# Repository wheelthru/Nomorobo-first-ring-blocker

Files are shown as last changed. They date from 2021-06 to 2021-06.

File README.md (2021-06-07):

# First-ring blocker for Nomorobo

This tool blocks the first ring of all incoming calls, avoiding the annoying one-ring-and-silence from calls the great Nomorobo service blocks. This is at the cost of real callers having to wait one extra ring before we pick up.  Oh Well.

## Description

The real documentation of this project is here: [http://jimlaurwilliams.org/wordpress/?p=6738](http://jimlaurwilliams.org/wordpress/?p=6738) 

Its ATtiny85 basically controls a normally closed relay in series with the incoming phone line (here a VOIP ATA), opening the contacts a few milliseconds into the first ring, before phones can ring.  It reconnects quickly after the first ring, in hopes of not screwing with the Caller ID sent between rings.

This was built and tuned for my situation, with parts from my junkbox, and probably isn't a drop-in for anybody else.  OK, maybe if they have a Arris TG1682G modem providing their VOIP phone connections.  It was posted here at the request of someone who saw the post in my Project Notes.

The Eagle (7.7.0) files for the PCB I made up for mine are included here.  Unless your junkbox contains the same parts as mine, the board layout probably isn't useful.

Code for the ATtiny85 on the PCB, developed with Arduino IDE 1.8.x, is  in **Nomorobo85Msg.ino**.  A Nano displays stats (rings, blocks) on a 1620 LCD.  Serial communication from the main PCB (via SoftwareSerial) tells the Nano what to show.  The Nano's code is **LcdHostNanoMsg1.ino**.  There are various comments and historical leftovers in both those files.

## Author

Jim Williams (a member of [Workshop88](http://workshop88.com))

## Acknowledgments

Inspired as an improvement on the very useful [Nomorobo](https://www.nomorobo.com/) service.

Special thanks to Aaron Foss for the cool Nomorobo T shirt!

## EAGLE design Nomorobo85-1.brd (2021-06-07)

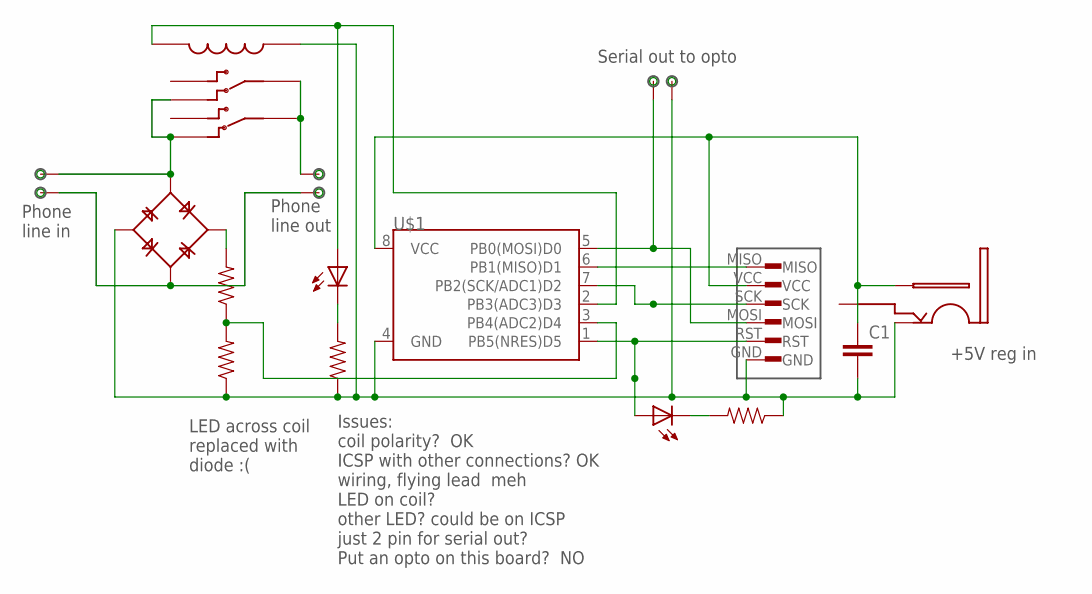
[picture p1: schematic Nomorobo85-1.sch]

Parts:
C1: CAP1206; 1206
U$1: ATTINY85SO08-I-HAVE-THESE; SO08-EIAJ
U$2, U$3, U$4, U$9: RESISTOR1206WW; 1206WW
U$5: BRIDGE-ROUNDMY-600V-1A; BRIDGE-ROUND
U$6: M2X3-HEADERICSP-LONGPADS; M2X3-LONGPADS
U$7, U$8: SOLDER-PAD-2LONGPADS; 02P
U$10: BARREL-COAX-PWR; BARREL-COAX-CONNECTOR
U$11, U$14: LED-12061206; 1206W
U$12: RELAY-DPDT
U$13: SOLDER-PAD-2LONGPPAD2; SOLDER-PAD-2-LONGPADS

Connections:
GND: C1.2, U$1.4 (GND), U$2.1, U$4.1, U$5.OUT- (V-), U$6.GND, U$9.1, U$10.SHELL, U$12.COIL+, U$13.P$2
unnamed: U$1.1 (PB5(NRES)D5), U$6.RST, U$14.1 (A)
unnamed: U$5.AC1 (IN1), U$7.1, U$12.NC1, U$12.NC2
unnamed: U$1.5 (PB0(MOSI)D0), U$6.MOSI, U$13.P$3
unnamed: U$1.2 (PB3(ADC3)D3), U$11.1 (A), U$12.COIL-
unnamed: U$1.6 (PB1(MISO)D1), U$6.MISO
unnamed: U$8.2, U$12.COM1, U$12.COM2
unnamed: U$1.3 (PB4(ADC2)D4), U$3.1, U$4.2
unnamed: U$3.2, U$5.OUT+ (V+)
unnamed: U$9.2, U$11.2 (C)
unnamed: U$5.AC2 (IN2), U$7.2, U$8.1
unnamed: U$2.2, U$14.2 (C)
unnamed: U$1.7 (PB2(SCK/ADC1)D2), U$6.SCK
VCC: C1.1, U$1.8 (VCC), U$6.VCC, U$10.PIN

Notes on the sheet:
Serial out to opto
+5V reg in
Phone line in
Phone line out
Issues: coil polarity? OK ICSP with other connections? OK wiring, flying lead meh LED on coil? other LED? could be on ICSP just 2 pin for serial out? Put an opto on this board? NO
LED across coil replaced with diode :(

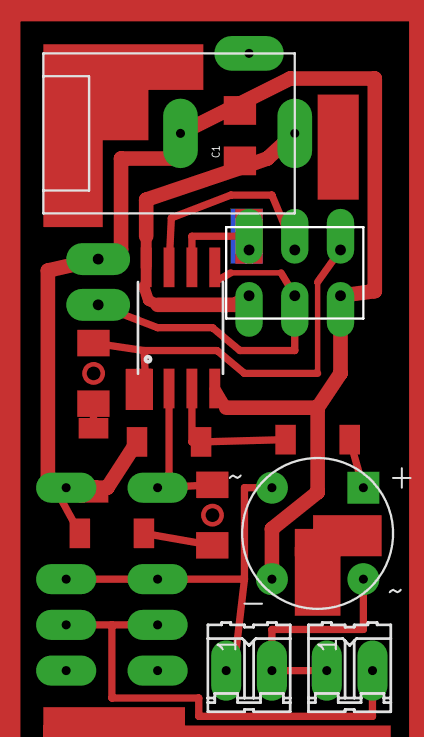
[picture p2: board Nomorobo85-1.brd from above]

Board: 2 copper layers, 15 parts (1 on the bottom side), 14 nets.

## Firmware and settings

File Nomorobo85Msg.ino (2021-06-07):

/* Nomorobo first ring stopper  started 12/30/19
 *  Production version, hosted on Tiny85.
 *  Operates a relay to disconnect all house phones
 *  on first ring.  If NMR blocks a call, we'll never hear
 *  anything.  If it lets the call thru, we need to look
 *  right away, just like in the old days.
 *  
 *  This is designed for our VOIP phones, with 2.0 sec
 *  of 20Hz 90VAC ring on top of 48VDC, 4 sec off.  We turn on
 *  a relay to open the line to the rest of the house phones as
 *  soon as we detect a ring - a few ms.  We watch each half cycle
 *  of the ring (full wave rectified thru a bridge) and detect 
 *  end of ring when we're not retriggered in 25ms or so.
 *  
 *  After first ring is over the NC relay is released, reconnecting
 *  all the house phones.  While that lets caller ID thru, since
 *  phones didn't hear a ring, they're not listening for caller ID
 *  until the next ring.
 *  
 *  Voltage divider (33K/1.5K) is set for 2.56V reference.
 *  
 *  The analog in line can be in one of 3 states:
 *  - 48V, on hook, idle
 *  - ringing: A/D 1023 ~15ms, < THRESH ~10ms
 *  - ~10V, off hook
 *  
 *  There's a ~4ms glitch of ~60V (enough to look like a ring) going from 
 *  off hook to on hook.  We have to protect against that being interpreted
 *  as a ring.  It would look like a NMR one ringer, and get a false count.
 *  
 *  The state machine has 3 states:
 *  - WAITING: 99% of time here.  48VDC, waiting for first ring
 *  - FIRSTRING: line voltage > THRESH within last 35ms, relay open
 *  - HOLDOFF: relay closed, won't retrigger and reopen relay; blue LED on;
 *    exit this state with continuous 5 sec idle.
 * ------------------------------------------------
 * Tiny85 version also counts rings and blocks and sends those stats out via
 * 1200B software serial to an opto isolated input on a 485 net node.  Because
 * the opto is an inverter, we use Software Serial's optional last param to invert.
 * Protocol is modeled after Basement Watchdog Big Dog voltage monitor:
 * - 0x55 header
 * - one byte # rings this message
 * - one byte # blocks this message
 * - one byte checksum
 * 
 * As an interim implementation, it sends ASCII text with some privately
 * defined controls to another Arduino that runs an LCD for display.  A few
 * lines of code change (in one function) and it will talk to a 485 node
 * thru the isolator.  Real Soon Now.
 * 
 * Nomorobo85Msg: changes from strings to formatted message 1/10/20 - works
 */

#include <jim.h>
#include <SoftwareSerial.h>


// hardware pin definitions
#define INPIN A2
#define RELAY 3
#define BLUELED 2
#define TXPIN 0
#define DONTCARE 1
#define HEADER (0x55)

// A/D min value if ringing 
#define THRESH 1020
// A/D max value if off hook
#define OFFHOOKVAL 400
// worst case time since last ring before declaring ring done, ms
#define RINGSTOPPED 35
// escape from HOLDOFF if idle continuously for this long
#define HOLDOFFTIME 5000

  SoftwareSerial myserial(DONTCARE,TXPIN,0);  // last param=1 to invert thru opto


void setup() {
  pinMode (BLUELED, OUTPUT);
  blink(BLUELED,20);
  delay(100);
  blink(BLUELED,20);
  pinMode(RELAY,OUTPUT);
  analogReference(INTERNAL2V56_NO_CAP);  // 2.56V on Tiny85
  myserial.begin(1200);
  //myserial.println("hello");

}// end setup


  enum l {idle,ring,offhook}line;
  int rings=0,nmrblocks=0;


//=============== MAIN LOOP =================
void loop() {
  long currmillis,lastring,lastspin,holdstart;
  int val,oldval=848;
  enum states {WAITING=0,FIRSTRING=1,HOLDOFF=2} state;
  bool morerings,doannounce; // true if ring during holdoff, if announce when done

  state=WAITING;
  
  while(1){
    currmillis=millis();
    // reduce noise with rolling average
    val=(analogRead(INPIN)+(oldval*5)+3)/6;
    oldval=val;
    // assign physical state of line
    line=idle;
    if(val>THRESH)line=ring;
    if(val<OFFHOOKVAL)line=offhook;
    
    //------ HANDLE DETECTED RING: VOLTAGE > THRESH ----
    if(line==ring){
      switch (state){
        case WAITING: // waiting for a ring - got one!
          digitalWrite(RELAY,HIGH); // block that ring!
          state=FIRSTRING;
          lastring=currmillis;    // need to know time since last ring pulse
          rings++;        // fact
          nmrblocks++;    // optimistic guess; fix later if wrong
          morerings=FALSE;  // don't count as NMR block if more rings
          break;
          
        case FIRSTRING: //actively in first ring
          lastring=currmillis;  // reset retrigger timer
          break;
          
        case HOLDOFF: // relay closed again
          morerings=TRUE;   // only matters if doannounce is true
          holdstart=currmillis; // reset timer
          break;
        default:
        ;
      }//end switch
     }//end if ringing; continue below with else not ringing


     //------ HANDLE VOLTAGE BELOW THRESH ------
     // could be idle, offhook, or a voltage dip during active ringing
     else { // idle OR offhook
      switch(state){
        case WAITING:   
          // Offline has a HV glitch when going onhook, so we just use HOLDOFF
          // so that glitch isn't perceived as a ring.
          if(line==offhook){
            state=HOLDOFF;
            doannounce=FALSE;
            holdstart=currmillis; //reset timer
            digitalWrite(BLUELED,HIGH);
          }//end if offhook
          // else boring 99% case
          break;
          
        case FIRSTRING:
          //Check for done ringing with timeout of > 1/2 positive cycle time
          if(currmillis-lastring > RINGSTOPPED){
            digitalWrite(RELAY,LOW);  // main reconnect
            state=HOLDOFF;  // don't detect ring until back to WAITING
            holdstart=currmillis; //reset timer
            doannounce=TRUE;  // only announce if we come in this way
            digitalWrite(BLUELED,HIGH); // visible indication of HOLDOFF state
            }//end if > RINGSTOPPED
            break;
            
        case HOLDOFF:
          // only way out is HOLDOFFTIME in idle state
          if(ring==offhook){holdstart=currmillis;}  // reset
          if(currmillis-holdstart > HOLDOFFTIME){
            state=WAITING;
            digitalWrite(BLUELED,LOW);
            if(doannounce){
              doannounce=FALSE;
              if(morerings)nmrblocks--;
              //announce(); //called in spinner
              }//end if doannounce
          }//end if > HOLDOFFTIME
            break; 
     }//end switch      
   }//end else voltage not > THRESH
      

    // SPINNER
    // was animate remote LCD
    // now, send data
    if(currmillis-lastspin > 2000){
     lastspin=currmillis+1;
     announce();
     //myserial.print('#');
   }//end lastspin
      
     
  }//end while
  
}// end loop()
//================================================



void blink(int pin,long dur){
  digitalWrite(pin,HIGH);
  delay(dur);
  digitalWrite(pin,LOW);  
}


// routine to annouce ring counts
void announce(){
// this is for messages
#if 1
  byte sum,b1,b2,b3,b4;
  b1=rings&0xff;
  b2=rings>>8;
  b3=nmrblocks&0xff;
  b4=nmrblocks>>8;
  myserial.write(HEADER);
  myserial.write(b1);
  myserial.write(b2);
  myserial.write(b3);
  myserial.write(b4);
  sum=b1+b2+b3+b4;  // sum is only a byte, so auto truncates
  myserial.write(sum);
  myserial.write(0xa);
#endif

// this is for remote LCD
#if 0
  myserial.print("$Rings: ");
  myserial.print(rings);
  myserial.print("&NMR blocks: ");
  myserial.print(nmrblocks);
#endif
  
// This one's for the local LCD
#if 0
    lcd.home();
    lcd.clear();
    lcd.print("Rings: ");
    lcd.print(rings);
    lcd.setCursor(0, 1);
    lcd.print("NMR blocks: ");
    lcd.print(nmrblocks);  
#endif

}// end announce

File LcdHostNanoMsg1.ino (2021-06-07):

/* Quickie standalone Arduino to receive messages from
 * NMR first ring stopper and display on LCD.  Uses custom
 * chars for cursor/clear control
 * 1/6/20
 * LcdHostNanoMsg1: 
 * Added protocol for serial message from NMR controller 1/10/20  works
*/

#include <LiquidCrystal_PCF8574.h>
#include <Wire.h>

LiquidCrystal_PCF8574 lcd(0x27); // set the LCD address to 0x27 for a 16 chars and 2 line display

#define HEADER (0x55)
int rings,nmrblocks;

int show = -1;

void setup()
{
  int error;

  Serial.begin(1200);
  //Serial.println("LCD...");


  // See http://playground.arduino.cc/Main/I2cScanner how to test for a I2C device.
  Wire.begin();
  Wire.beginTransmission(0x27);
  error = Wire.endTransmission();

  if (error == 0) {
    Serial.println(": LCD found at 0x27.");
    show = 0;
    lcd.begin(16, 2); // initialize the lcd

  } else {
    Serial.println(": LCD not found.");
  } // if

} // setup()


void loop()
{
  char blank16[]="                ";
  int bits[]={0,0x10,0x8,0x4,0x2,0x1,0x0,0},i;
  lcd.createChar(1,bits); // backslash at char pos 1
  char hbchar[]={'|','/','-',char(1)};
  static char errcnt='0';

    lcd.setBacklight(255);
    lcd.home();
    lcd.clear();
    lcd.print("Nomorobo LCD");
    delay(1000);

  while(1){
    int getvalret=getval();
    if(getvalret==-1)errcnt++;
    if(getvalret==1){
      lcd.setCursor(0,0);
      lcd.print(blank16);
      lcd.setCursor(0,0);
      lcd.print("rings: ");
      lcd.print(rings);
      
      lcd.setCursor(0,1);
      lcd.print(blank16);
      lcd.setCursor(0,1);
      lcd.print("NMR blocks: ");
      lcd.print(nmrblocks);
      
      lcd.setCursor(15,0);
      lcd.print(errcnt);
      lcd.setCursor(15,1);
      lcd.print(hbchar[i++]);
      if(i>3)i=0;
    }// end if got msg
    
  }//end while

  
} // loop()



//--------- READ NMR MESSAGE ---------
// return: -1=err; 0=nothing available; 1=got data
int getval(){
  static byte state=0;
  byte val;

  while(Serial.available()){
    val=Serial.read(); 
    switch(state){
      case 0: if(val==0x55)state=1; // waiting for header
      break;
      case 1: rings=val;  //got rings
        state=2;
        break;
      case 2: rings+=val<<8; // got nmrblocks
        state=3;
        break;
      case 3: nmrblocks=val;  //got rings
        state=4;
        break;
      case 4: nmrblocks+=val>>8; // got nmrblocks
        state=5;
        break;
     case 5: if(val==(byte)((rings&0xff)+(rings<<8)+(nmrblocks&0xff)+(nmrblocks<<8))){ // check sum
        state=6;
        }else{state=99;}  //fail
        break;
      case 6: if(val==0xa){
        state=0;
        return 1;
      }else{state=99;}
      break;
      default :
        state=99;
    }//end switch
  }// end while
 
  if(state==99){
    state=0;
    return -1;
  }//end if 99
 return 0; 
}// end getval

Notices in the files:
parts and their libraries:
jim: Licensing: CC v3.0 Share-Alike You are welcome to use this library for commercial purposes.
